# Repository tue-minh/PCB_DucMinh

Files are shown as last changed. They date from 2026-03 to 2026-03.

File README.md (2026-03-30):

<div align="center">
  <a href="image/pcb.jpg" target="_blank">
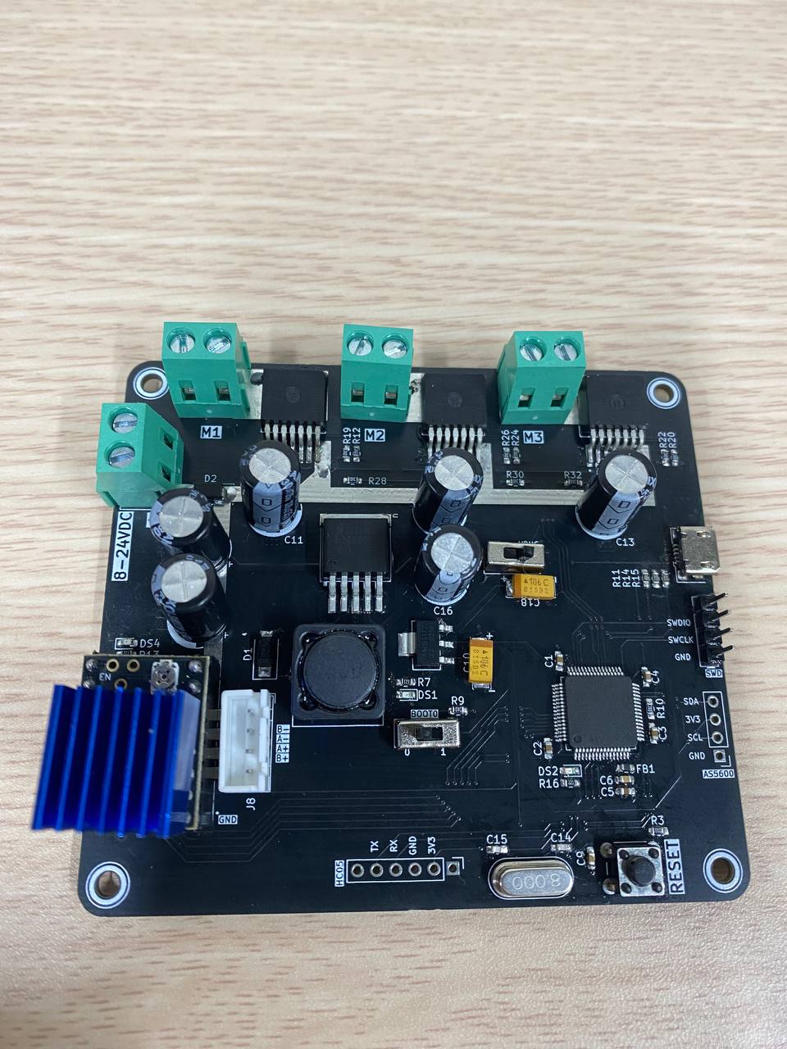
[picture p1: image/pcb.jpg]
Hardware Review
    
  </a>
  <p style="margin-top: 10px; color: #555; font-size: 0.9em; font-style: italic;">
    🔍 <b>Fig.</b> Hardware Review.
  </p>
</div>

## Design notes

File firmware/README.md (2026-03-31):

# Hướng dẫn sử dụng lệnh điều khiển

## 1. Điều khiển Stepper Motor

| Chức năng | Lệnh | Mô tả |
|---|---|---|
| Enable/Disable Driver | `step on` | Bật driver |
| | `step off` | Tắt driver |
| Set Direction | `step dir 0` | CCW
| | `step dir 1` | CW
| Set Speed | `step speed x` | Đặt tốc độ<br>*Lưu ý: 0 < x ≤ 10000* |
| Set MicroStep | `step ms x y` | Cài đặt MicroStep<br>**x**: 1/2 (MS1/MS2)<br>**y**: 1/0 (On/Off) |
| Enable PWM Output | `step start` | Bật xuất PWM |
| Disable PWM Output | `step stop` | Tắt xuất PWM |

## 2. Điều khiển DC Motor

| Chức năng | Lệnh | Mô tả |
|---|---|---|
| Set Speed (Single Channel) | `dc ch 1 x` | Đặt tốc độ cho kênh 1 <br>*Lưu ý: 0 < x ≤ 999* |
| | `dc ch 2 x` | Đặt tốc độ cho kênh 2 <br>*Lưu ý: 0 < x ≤ 999 |
| | `dc ch 3 x` | Đặt tốc độ cho kênh 3 <br>*Lưu ý: 0 < x ≤ 999 |
| Enable PWM Output | `dc start 1` | Bật PWM cho kênh 1 |
| | `dc start 2` | Bật PWM cho kênh 2 |
| | `dc start 3` | Bật PWM cho kênh 3 |
| Disable PWM Output | `dc stop 1` | Tắt PWM cho kênh 1 |
| | `dc stop 2` | Tắt PWM cho kênh 2 |
| | `dc stop 3` | Tắt PWM cho kênh 3 |

**Ghi chú:**
- Các lệnh `dc ch` dùng để đặt tốc độ cho từng kênh riêng lẻ.
- Các lệnh `dc start` dùng để bật xuất PWM cho từng kênh.

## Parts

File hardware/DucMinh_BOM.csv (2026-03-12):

Reference | Value | Footprint | Qty
C1,C2,C3,C4,C5,C9 | 100nf | Capacitor_SMD:C_0603_1608Metric_Pad1.08x0.95mm_HandSolder | 6 | Có s?n
C6 | 1uf | Capacitor_SMD:C_0603_1608Metric_Pad1.08x0.95mm_HandSolder | 1
C8,C16 | 330uF | Capacitor_THT:CP_Radial_D8.0mm_P5.00mm | 2
C10,C18 | 10uf | tue_tantalum6032:tue_tantalum_6032 | 2 | Thi?u
C11,C12,C13 | 330uf | Capacitor_THT:CP_Radial_D8.0mm_P5.00mm | 3
C14,C15 | 20pf | Capacitor_SMD:C_0603_1608Metric_Pad1.08x0.95mm_HandSolder | 2 | Có s?n
C17 | 470uf | Capacitor_THT:CP_Radial_D8.0mm_P5.00mm | 1 | Thi?u
D1,D2 | SS34 | Diode_SMD:D_SMA | 2
DS1 | LED_PWR | LED_SMD:LED_0603_1608Metric_Pad1.05x0.95mm_HandSolder | 1 | Có s?n
DS2 | LED_PC13 | LED_SMD:LED_0603_1608Metric_Pad1.05x0.95mm_HandSolder | 1
DS4 | LED_TMC_EN | LED_SMD:LED_0603_1608Metric_Pad1.05x0.95mm_HandSolder | 1
FB1 | 120R | Resistor_SMD:R_0603_1608Metric | 1
J1 | Power | tue_TerminalBlock:TerminalBlock_bornier-2_P5.08mm | 1
J2 | M1 | tue_TerminalBlock:TerminalBlock_bornier-2_P5.08mm | 1
J3 | USB_B_Micro | Connector_USB:USB_Micro-B_Amphenol_10118193-0001LF_Horizontal | 1
J4 | M2 | tue_TerminalBlock:TerminalBlock_bornier-2_P5.08mm | 1
J5 | M3 | tue_TerminalBlock:TerminalBlock_bornier-2_P5.08mm | 1
J6 | AS5600 | Connector_PinHeader_2.54mm:PinHeader_1x04_P2.54mm_Vertical | 1
J7 | STLink | Connector_PinHeader_2.54mm:PinHeader_1x04_P2.54mm_Vertical | 1
J8 | Stepper_Motor | Connector_JST:JST_XH_B4B-XH-A_1x04_P2.50mm_Vertical | 1
J10 | HC05 | Connector_PinHeader_2.54mm:PinHeader_1x06_P2.54mm_Vertical | 1
J11 | PWR_Selection | tue_switch-SS12D00:tue_SS12D00_3P_2.5mm | 1 | Thi?u
J12 | BOOT0 | tue_switch-SS12D00:tue_SS12D00_3P_2.5mm | 1
L1 | CDRH127/LDNP-47uH | tue_inductor_smd:tue__CDRH127LDNP-470MC_SUM | 1
R3,R9,R10,R12,R19,R20,R22,R24,R26,R28,R30,R32 | 10k | Resistor_SMD:R_0603_1608Metric_Pad0.98x0.95mm_HandSolder | 12 | Có s?n
R7,R13,R16 | 1k | Resistor_SMD:R_0603_1608Metric_Pad0.98x0.95mm_HandSolder | 3
R11 | 1k5 | Resistor_SMD:R_0603_1608Metric_Pad0.98x0.95mm_HandSolder | 1
R14,R15 | 20-22R | Resistor_SMD:R_0603_1608Metric_Pad0.98x0.95mm_HandSolder | 2
SW1 | SW_Push | Button_Switch_THT:SW_PUSH_6mm | 1
U2 | AMS1117-3.3 | tue_ams1117:SOT_AMS_ADS | 1 | Thi?u
U3 | LM2596SX-5.0/NOPB | tue_lm2596hvs:tue_lm2596 | 1
U4 | TMC2209_SILENTSTEPSTICK | tue_TMC2209:tue_TMC2209 | 1
U5,U8,U10 | BTS7960B | tue_bts7960b:DPAK127P1490X440-8N | 3
U6 | STM32F103RCT6 | tue_stm32f103rct6:QFP50P1200X1200X160-64N | 1
Y1 | 8 MHz | Crystal:Crystal_HC49-4H_Vertical | 1

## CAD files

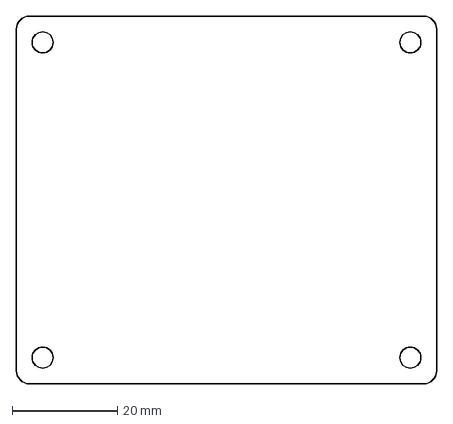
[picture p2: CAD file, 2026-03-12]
hardware/Drawing1.dxf
80.0 x 70.0 mm

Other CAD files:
hardware/Drawing1.dwg

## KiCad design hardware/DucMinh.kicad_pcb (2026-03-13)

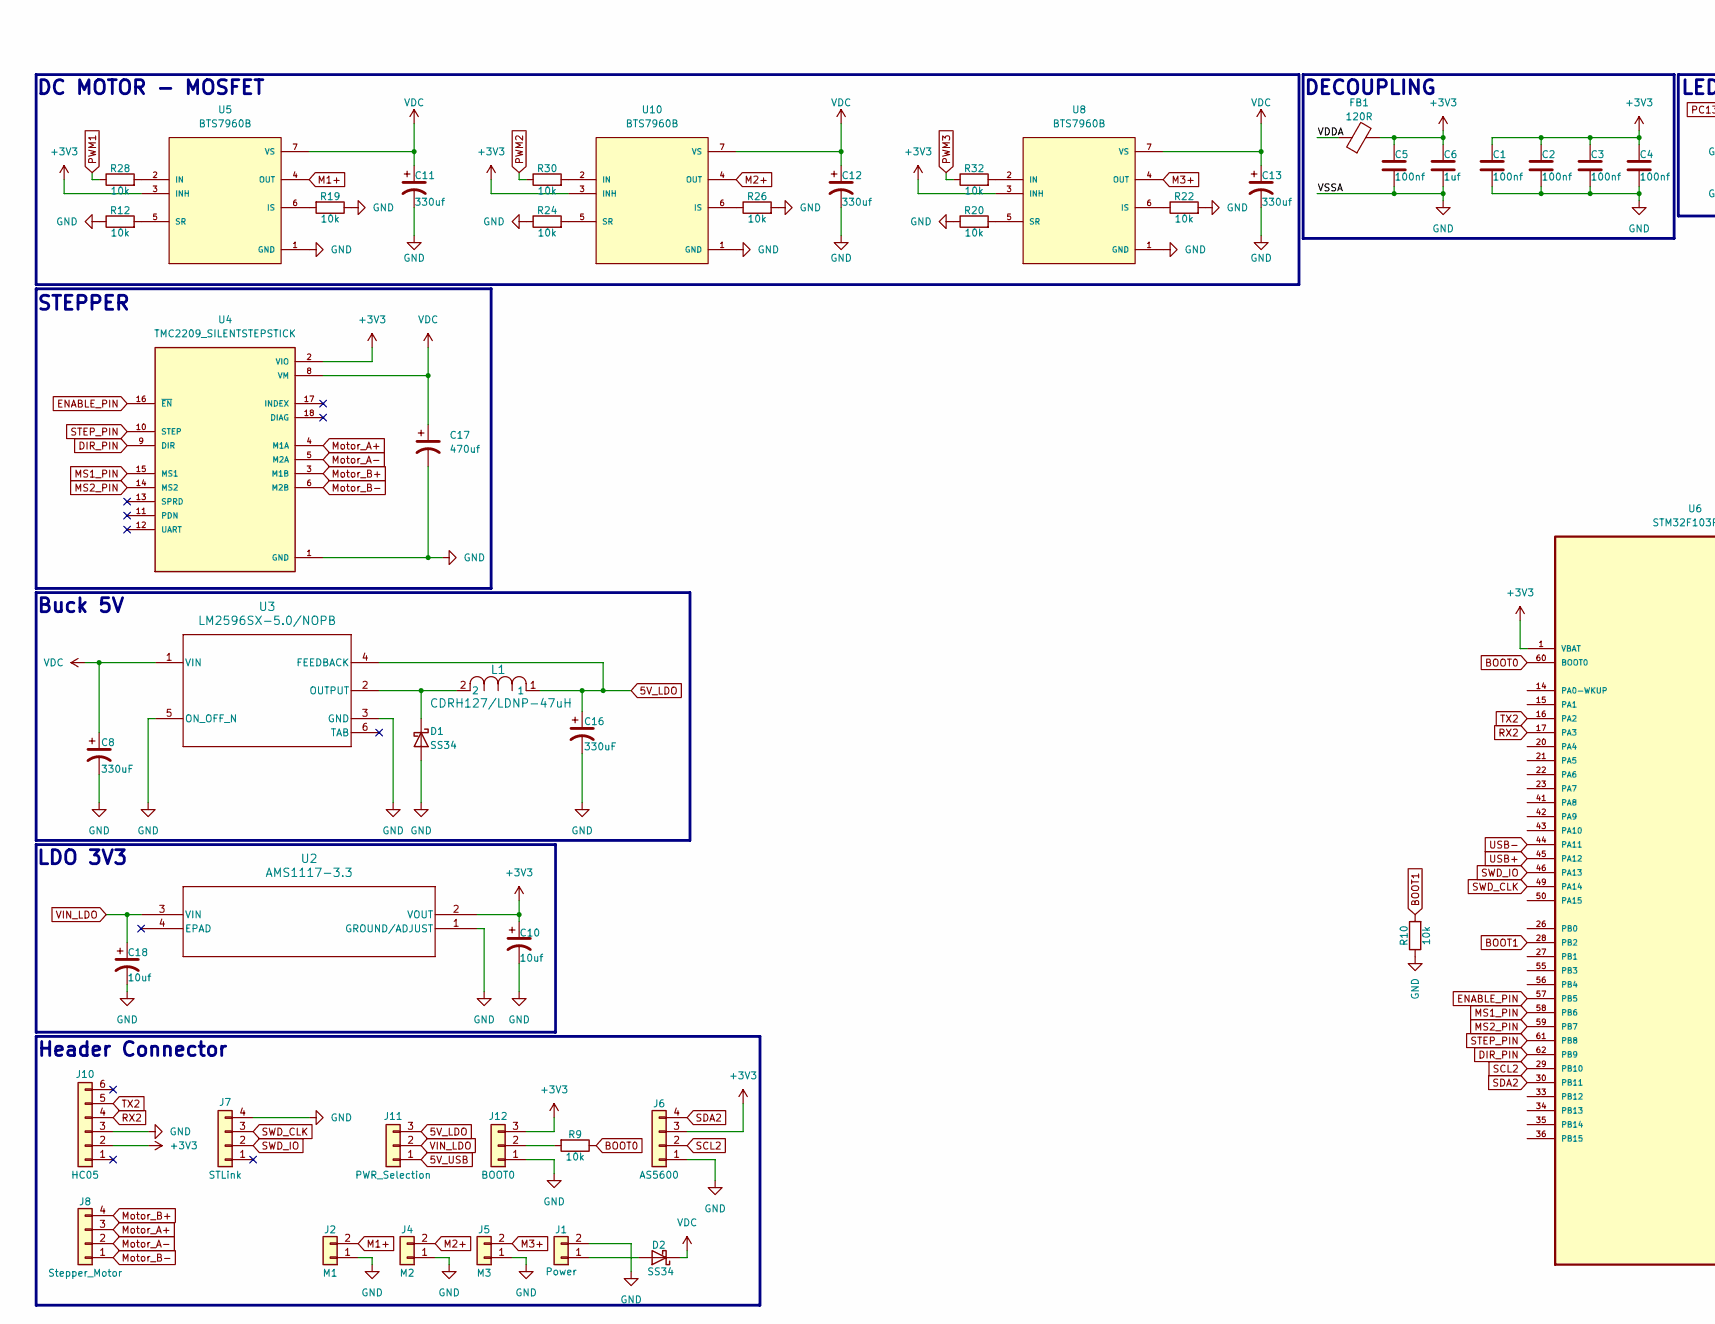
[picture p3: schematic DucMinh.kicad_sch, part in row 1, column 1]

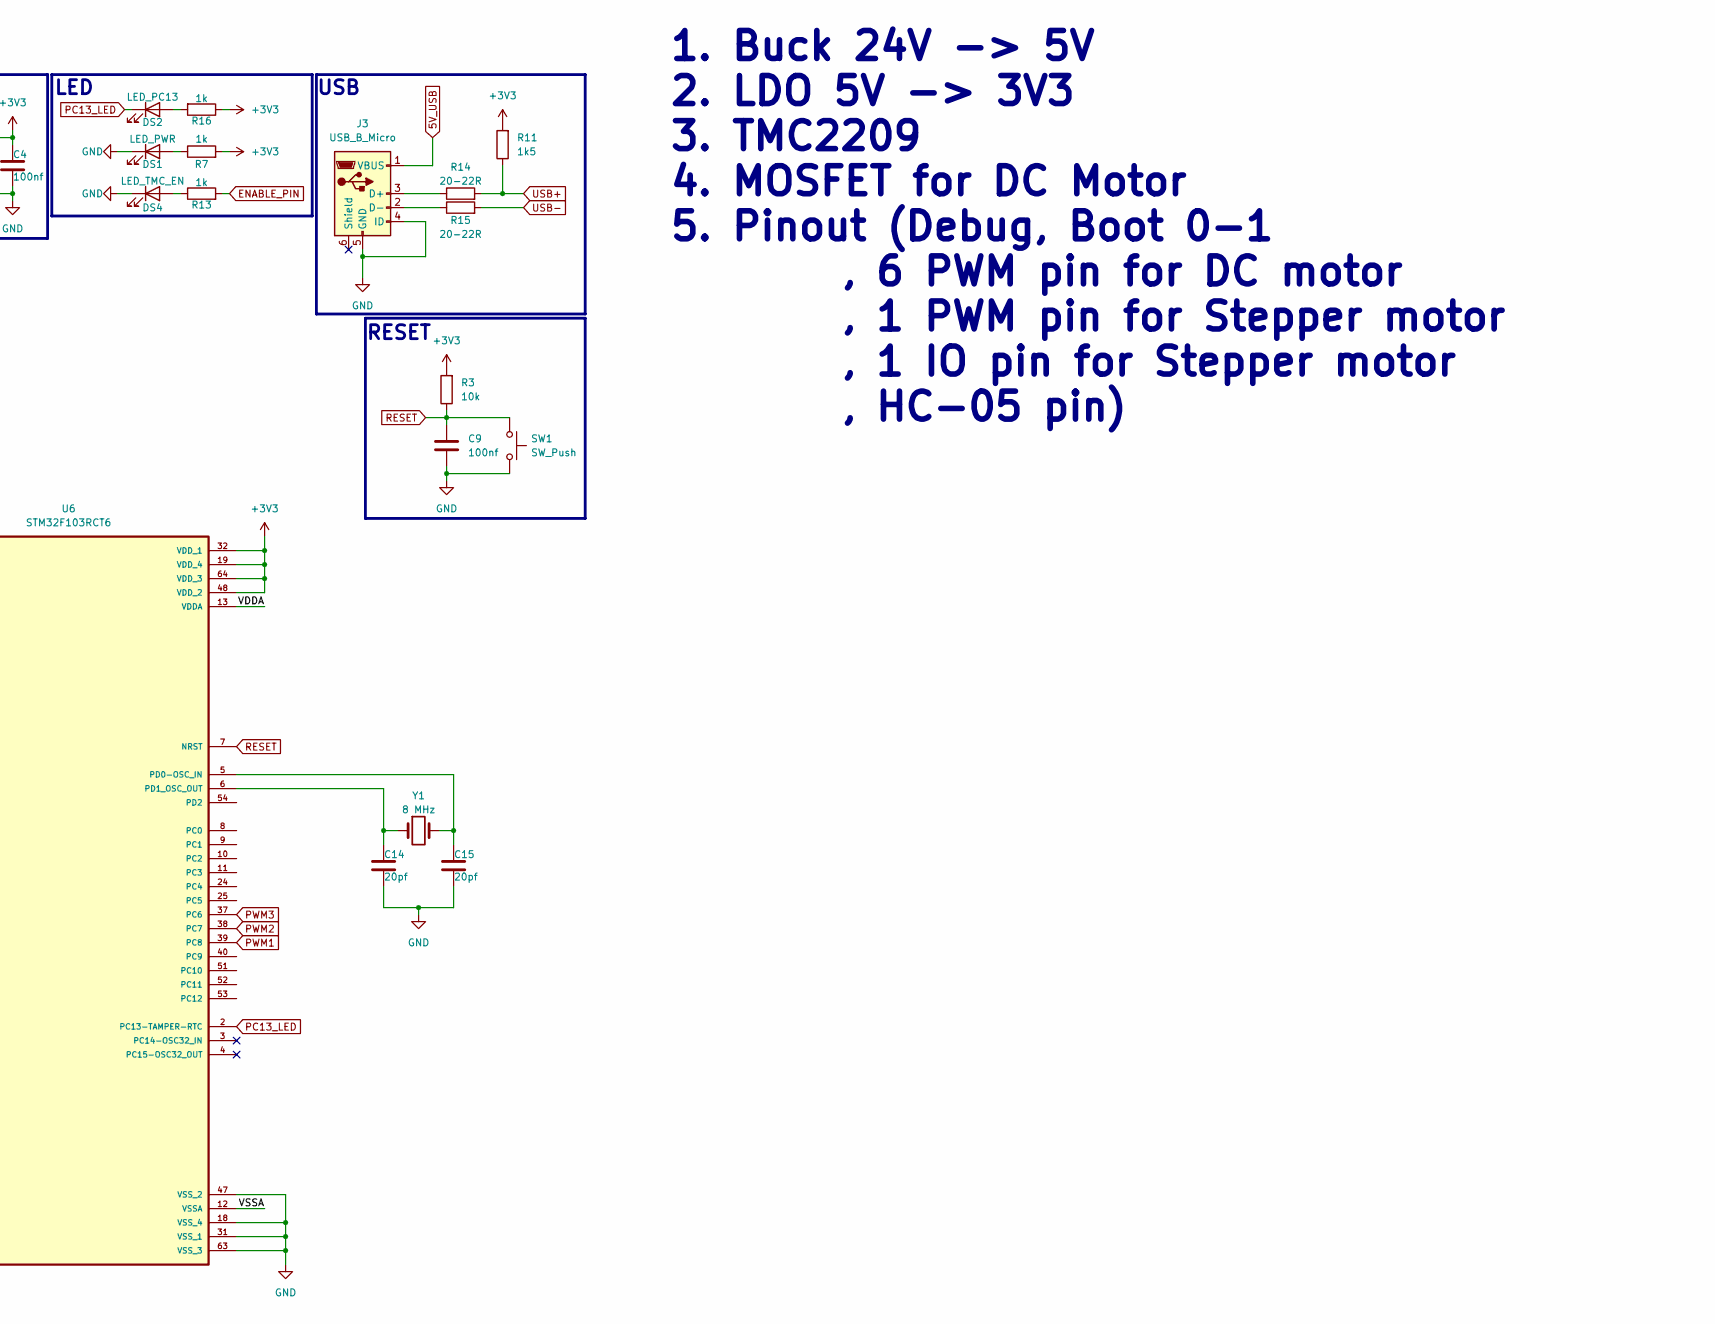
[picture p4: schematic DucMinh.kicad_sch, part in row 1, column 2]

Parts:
C1, C2, C3, C4, C5, C9: 100nf; C_0603_1608Metric_Pad1.08x0.95mm_HandSolder
C6: 1uf; C_0603_1608Metric_Pad1.08x0.95mm_HandSolder
C8, C16: 330uF; CP_Radial_D8.0mm_P5.00mm
C10, C18: 10uf; tue_tantalum_6032
C11, C12, C13: 330uf; CP_Radial_D8.0mm_P5.00mm
C14, C15: 20pf; C_0603_1608Metric_Pad1.08x0.95mm_HandSolder
C17: 470uf; CP_Radial_D8.0mm_P5.00mm
D1, D2: SS34; D_SMA
DS1: LED_PWR; LED_0603_1608Metric_Pad1.05x0.95mm_HandSolder
DS2: LED_PC13; LED_0603_1608Metric_Pad1.05x0.95mm_HandSolder
DS4: LED_TMC_EN; LED_0603_1608Metric_Pad1.05x0.95mm_HandSolder
FB1: 120R; R_0603_1608Metric
J1: Power; TerminalBlock_bornier-2_P5.08mm
J2: M1; TerminalBlock_bornier-2_P5.08mm
J3: USB_B_Micro; USB_Micro-B_Amphenol_10118193-0001LF_Horizontal
J4: M2; TerminalBlock_bornier-2_P5.08mm
J5: M3; TerminalBlock_bornier-2_P5.08mm
J6: AS5600; PinHeader_1x04_P2.54mm_Vertical
J7: STLink; PinHeader_1x04_P2.54mm_Vertical
J8: Stepper_Motor; JST_XH_B4B-XH-A_1x04_P2.50mm_Vertical
J10: HC05; PinHeader_1x06_P2.54mm_Vertical
J11: PWR_Selection; tue_SS12D00_3P_2.5mm
J12: BOOT0; tue_SS12D00_3P_2.5mm
L1: CDRH127/LDNP-47uH; tue__CDRH127LDNP-470MC_SUM
R3, R9, R10, R12, R19, R20, R22, R24, R26, R28, R30, R32: 10k; R_0603_1608Metric_Pad0.98x0.95mm_HandSolder
R7, R13, R16: 1k; R_0603_1608Metric_Pad0.98x0.95mm_HandSolder
R11: 1k5; R_0603_1608Metric_Pad0.98x0.95mm_HandSolder
R14, R15: 20-22R; R_0603_1608Metric_Pad0.98x0.95mm_HandSolder
SW1: SW_Push; SW_PUSH_6mm
U2: AMS1117-3.3; SOT_AMS_ADS
U3: LM2596SX-5.0/NOPB; tue_lm2596
U4: TMC2209_SILENTSTEPSTICK; tue_TMC2209; PARTREV 1.20
U5, U8, U10: BTS7960B; DPAK127P1490X440-8N; PARTREV 1.1
U6: STM32F103RCT6; QFP50P1200X1200X160-64N
Y1: 8 MHz; Crystal_HC49-4H_Vertical

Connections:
5V_LDO: C16.1, J11.3, L1.1, U3.4 (FEEDBACK)
5V_USB: J3.1 (VBUS), J11.1
+3V3: C1.1, C2.1, C3.1, C4.1, C5.1, C6.1, C10.1, FB1.2, J6.3, J10.2, J12.3, R3.2, R7.2, R11.2, R16.1, U2.2 (VOUT), U4.2 (VIO), U5.3 (INH), U6.1 (VBAT), U6.19 (VDD_4), U6.32 (VDD_1), U6.48 (VDD_2), U6.64 (VDD_3), U8.3 (INH), U10.3 (INH)
/VDDA: FB1.1, U6.13 (VDDA)
BOOT0: R9.1, U6.60 (BOOT0)
BOOT1: R10.2, U6.28 (PB2)
DIR_PIN: U4.9 (DIR), U6.62 (PB9)
ENABLE_PIN: R13.2, U4.16 (~EN), U6.57 (PB5)
GND: C1.2, C2.2, C3.2, C4.2, C5.2, C6.2, C8.2, C9.2, C10.2, C11.2, C12.2, C13.2, C14.2, C15.2, C16.2, C17.2, C18.2, D1.2 (A), DS1.1 (K), DS4.1 (K), J1.2, J2.1, J3.4 (ID), J3.5 (GND), J4.1, J5.1, J6.1, J7.4, J10.3, J12.1, R10.1, R12.1, R19.1, R20.1, R22.2, R24.1, R26.2, SW1.2, U2.1 (GROUND/ADJUST), U3.3 (GND), U3.5 (ON_OFF_N), U4.1 (GND), U4.7 (GND), U5.1 (GND), U6.12 (VSSA), U6.18 (VSS_4), U6.31 (VSS_1), U6.47 (VSS_2), U6.63 (VSS_3), U8.1 (GND), U10.1 (GND)
M1+: J2.2, U5.4 (OUT), U5.8 (OUT)
M2+: J4.2, U10.4 (OUT), U10.8 (OUT)
M3+: J5.2, U8.4 (OUT), U8.8 (OUT)
MS1_PIN: U4.15 (MS1), U6.58 (PB6)
MS2_PIN: U4.14 (MS2), U6.59 (PB7)
Motor_A+: J8.3, U4.4 (M1A)
Motor_A-: J8.2, U4.5 (M2A)
Motor_B+: J8.4, U4.3 (M1B)
Motor_B-: J8.1, U4.6 (M2B)
unnamed: D1.1 (K), L1.2, U3.2 (OUTPUT)
unnamed: D2.2 (A), J1.1
unnamed: DS1.2 (A), R7.1
unnamed: DS2.2 (A), R16.2
unnamed: DS4.2 (A), R13.1
unnamed: J3.3 (D+), R14.1
unnamed: J3.2 (D-), R15.1
unnamed: J12.2, R9.2
unnamed: R28.2, U5.2 (IN)
unnamed: R19.2, U5.6 (IS)
unnamed: R12.2, U5.5 (SR)
unnamed: C15.1, U6.5 (PD0-OSC_IN), Y1.2
unnamed: C14.1, U6.6 (PD1_OSC_OUT), Y1.1
unnamed: R32.2, U8.2 (IN)
unnamed: R22.1, U8.6 (IS)
unnamed: R20.2, U8.5 (SR)
unnamed: R30.2, U10.2 (IN)
unnamed: R26.1, U10.6 (IS)
unnamed: R24.2, U10.5 (SR)
PC13_LED: DS2.1 (K), U6.2 (PC13-TAMPER-RTC)
PWM1: R28.1, U6.39 (PC8)
PWM2: R30.1, U6.38 (PC7)
PWM3: R32.1, U6.37 (PC6)
RESET: C9.1, R3.1, SW1.1, U6.7 (NRST)
RX2: J10.4, U6.17 (PA3)
SCL2: J6.2, U6.29 (PB10)
SDA2: J6.4, U6.30 (PB11)
STEP_PIN: U4.10 (STEP), U6.61 (PB8)
SWD_CLK: J7.3, U6.49 (PA14)
SWD_IO: J7.2, U6.46 (PA13)
TX2: J10.5, U6.16 (PA2)
USB+: R11.1, R14.2, U6.45 (PA12)
USB-: R15.2, U6.44 (PA11)
VDC: C8.1, C11.1, C12.1, C13.1, C17.1, D2.1 (K), U3.1 (VIN), U4.8 (VM), U5.7 (VS), U8.7 (VS), U10.7 (VS)
VIN_LDO: C18.1, J11.2, U2.3 (VIN)

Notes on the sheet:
DECOUPLING
Buck 5V
LDO 3V3
RESET
STEPPER
Header Connector
1. Buck 24V -> 5V 2. LDO 5V -> 3V3 3. TMC2209 4. MOSFET for DC Motor 5. Pinout (Debug, Boot 0-1 , 6 PWM pin for DC motor , 1 PWM pin for Stepper motor , 1 IO pin for Stepper motor , HC-05 pin)
DC MOTOR - MOSFET
LED
USB

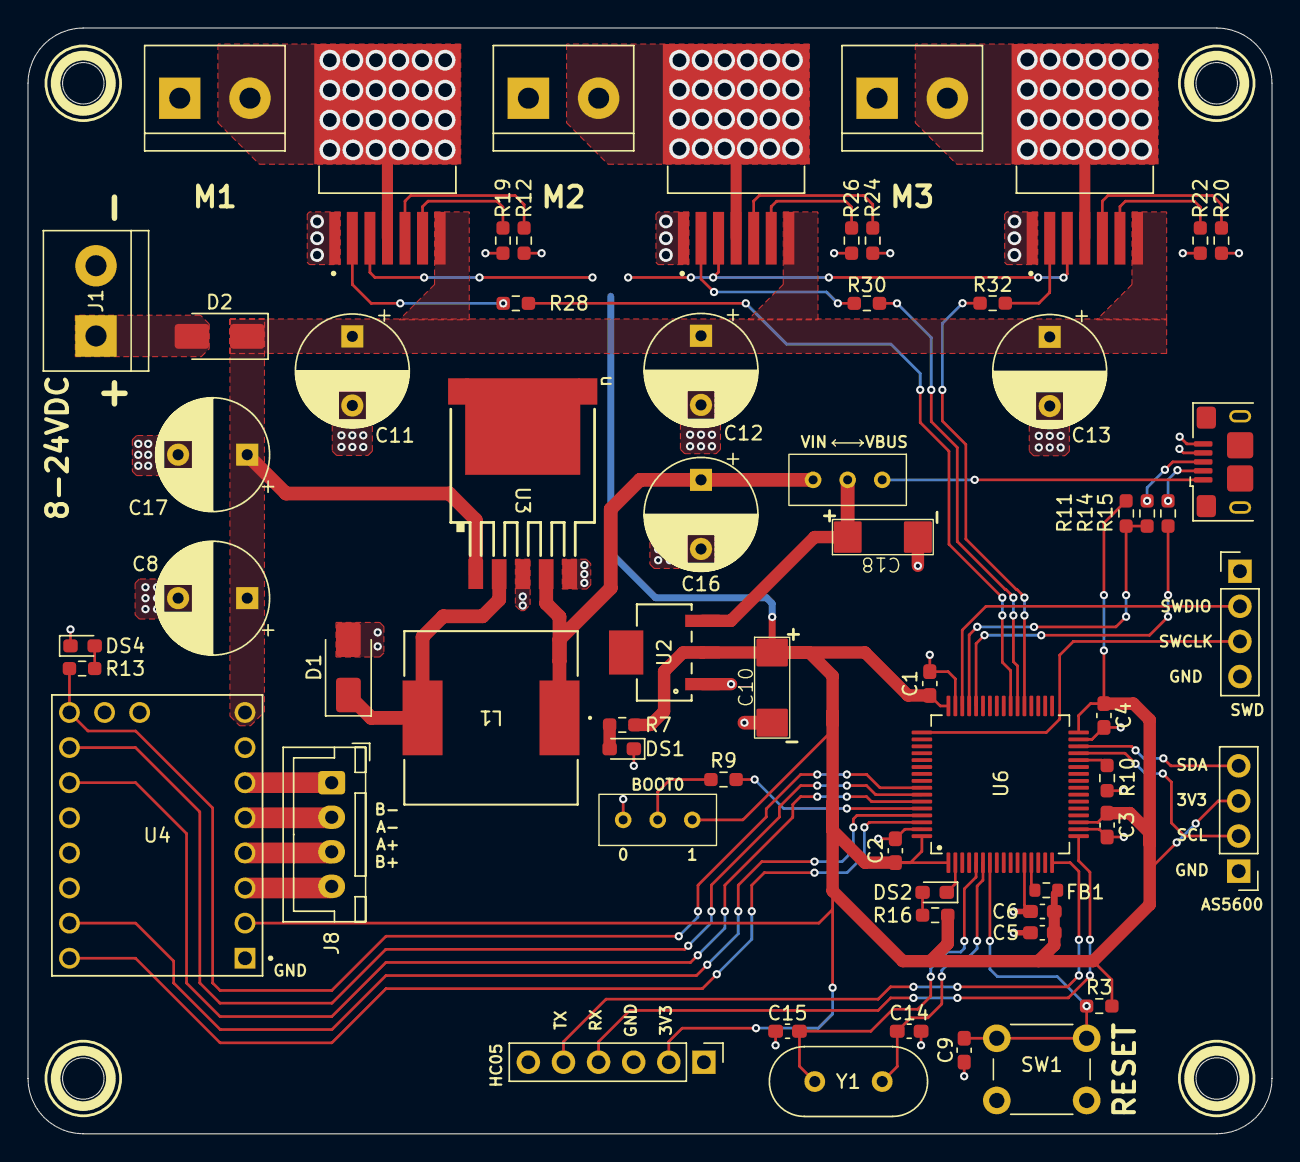
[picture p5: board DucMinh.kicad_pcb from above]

Board: 2 copper layers, 90.0 x 80.0 mm, 62 parts (0 on the bottom side), 53 nets.

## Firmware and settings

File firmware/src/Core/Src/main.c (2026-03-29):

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
/* Includes ------------------------------------------------------------------*/
#include "main.h"
#include "tim.h"
#include "usb_device.h"
#include "gpio.h"

/* USER CODE BEGIN Includes */
#include "usbd_cdc_if.h"
#include <stdio.h>
#include <string.h>
#include <stdlib.h>
#include <stdarg.h>
/* USER CODE END Includes */

/* USER CODE BEGIN PTD */
typedef struct
{
  char *data;
  uint32_t length;
} String;
typedef struct
{
  char *name;
  void (*handler)(int argc, char **argv);
  char *description;
} Command_t;
/* USER CODE END PTD */

/* USER CODE BEGIN PD */
#define STEP_PWM_PERIOD 1000
#define SERIAL_BUFFER_SIZE 256
/* USER CODE END PD */


/* USER CODE BEGIN PV */
static uint8_t serial_buffer[SERIAL_BUFFER_SIZE];
static uint32_t serial_buffer_index = 0;
static uint8_t serial_available_flag = 0;
uint8_t motor_speed = 0;
uint8_t stepper_enabled = 0;
uint8_t stepper_direction = 0;
uint32_t stepper_speed_hz = 100; // steps/seccond
/* USER CODE END PV */

void SystemClock_Config(void);
/* USER CODE BEGIN PFP */
uint8_t Serial_available(void);
int16_t Serial_read(void);
uint32_t Serial_readBytes(uint8_t *buffer, uint32_t length);
String Serial_readStringUntil(char terminator);
String Serial_readString(void);
int32_t Serial_parseInt(void);
float Serial_parseFloat(void);
// void Serial_print(const char *format, ...);
// void Serial_println(const char *format, ...);
// void Serial_print_int(int32_t value);
// void Serial_print_float(float value, uint8_t decimal_places);
// void Serial_println_void(void);
void Serial_flush(void);
void USB_CDC_RxHandler(uint8_t *Buf, uint32_t Len);
static void Stepper_Enable(void);
static void Stepper_Disable(void);
static void Stepper_Set_Direction(uint8_t dir);
static void Stepper_Set_Speed(uint32_t hz);
static void Stepper_Start(void);
static void Stepper_Stop(void);
// static void DC_Start(void);
// static void DC_Stop(void);
// static void DC_Set_Speed(uint8_t speed);

/* USER CODE END PFP */

/* USER CODE BEGIN 0 */
void USB_CDC_RxHandler(uint8_t *Buf, uint32_t Len)
{
  if (Len > 0)
  {
    for (uint32_t i = 0; i < Len; i++)
    {
      if (serial_buffer_index < SERIAL_BUFFER_SIZE)
      {
        serial_buffer[serial_buffer_index++] = Buf[i];
      }
    }
    serial_available_flag = 1;
  }
}
// Serial available - kiểm tra dữ liệu có sẵn
uint8_t Serial_available(void)
{
  return (serial_available_flag && (serial_buffer_index > 0));
}

static void Serial_write(uint8_t *data, uint16_t len)
{
  // gửi nếu USB rảnh, không thì bỏ
  if (CDC_Transmit_FS(data, len) == USBD_OK)
  {
  }
}
void Serial_print(const char *fmt, ...)
{
  char buffer[128];

  va_list args;
  va_start(args, fmt);
  vsnprintf(buffer, sizeof(buffer), fmt, args);
  va_end(args);

  Serial_write((uint8_t *)buffer, strlen(buffer));
}
void Serial_println(const char *fmt, ...)
{
  char buffer[128];

  va_list args;
  va_start(args, fmt);
  vsnprintf(buffer, sizeof(buffer), fmt, args);
  va_end(args);

  uint16_t len = strlen(buffer);

  // thêm newline
  buffer[len++] = '\r';
  buffer[len++] = '\n';
  buffer[len] = '\0';

  Serial_write((uint8_t *)buffer, len);
}

// Đọc 1 byte từ buffer
int16_t Serial_read(void)
{
  if (!Serial_available())
    return -1;

  uint8_t data = serial_buffer[0];

  // Dịch buffer lên
  for (uint32_t i = 0; i < serial_buffer_index - 1; i++)
  {
    serial_buffer[i] = serial_buffer[i + 1];
  }
  serial_buffer_index--;

  if (serial_buffer_index == 0)
  {
    serial_available_flag = 0;
  }

  return data;
}

// Đọc dữ liệu vào buffer
uint32_t Serial_readBytes(uint8_t *buffer, uint32_t length)
{
  uint32_t count = 0;
  while (count < length && Serial_available())
  {
    int16_t data = Serial_read();
    if (data >= 0)
    {
      buffer[count++] = (uint8_t)data;
    }
    else
    {
      break;
    }
  }
  return count;
}

// Đọc 1 dòng (đến \n hoặc \r\n)
String Serial_readStringUntil(char terminator)
{
  String result = {0};
  char temp[SERIAL_BUFFER_SIZE];
  uint32_t index = 0;

  while (index < SERIAL_BUFFER_SIZE - 1 && Serial_available())
  {
    int16_t c = Serial_read();
    if (c < 0)
      break;

    if (c == terminator || c == '\n')
    {
      if (c == '\n' && index > 0 && temp[index - 1] == '\r')
      {
        index--; // Bỏ qua \r
      }
      break;
    }

    temp[index++] = (char)c;
  }

  temp[index] = '\0';
  result.data = malloc(index + 1);
  if (result.data)
  {
    strcpy(result.data, temp);
    result.length = index;
  }

  return result;
}

// Đọc chuỗi (không có ký tự kết thúc)
String Serial_readString(void)
{
  return Serial_readStringUntil('\n');
}

// Parse string thành số nguyên
int32_t Serial_parseInt(void)
{
  String str = Serial_readStringUntil('\n');
  if (str.data)
  {
    int32_t value = atoi(str.data);
    free(str.data);
    return value;
  }
  return 0;
}

// Parse string thành số thực
float Serial_parseFloat(void)
{
  String str = Serial_readStringUntil('\n');
  if (str.data)
  {
    float value = atof(str.data);
    free(str.data);
    return value;
  }
  return 0;
}

// // In ra Serial (giống Serial.print)
// void Serial_print(const char *format, ...)
// {
//   char buffer[256];
//   va_list args;
//   va_start(args, format);
//   vsnprintf(buffer, sizeof(buffer), format, args);
//   va_end(args);

//   if (CDC_Transmit_FS((uint8_t *)buffer, strlen(buffer)) == USBD_OK){}
// }

// // In ra Serial có xuống dòng
// void Serial_println(const char *format, ...)
// {
//   char buffer[256];
//   va_list args;
//   va_start(args, format);
//   vsnprintf(buffer, sizeof(buffer), format, args);
//   va_end(args);

//   char output[260];
//   snprintf(output, sizeof(output), "%s\r\n", buffer);
//   if (CDC_Transmit_FS((uint8_t *)output, strlen(output)) == USBD_OK){}
// }

// // In số nguyên
// void Serial_print_int(int32_t value)
// {
//   char buffer[32];
//   snprintf(buffer, sizeof(buffer), "%ld", value);
//   if (CDC_Transmit_FS((uint8_t *)buffer, strlen(buffer)) == USBD_OK){}
// }

// // In số thực
// void Serial_print_float(float value, uint8_t decimal_places)
// {
//   char buffer[64];
//   snprintf(buffer, sizeof(buffer), "%.*f", decimal_places, value);
//   if (CDC_Transmit_FS((uint8_t *)buffer, strlen(buffer)) == USBD_OK){}
// }

// // In xuống dòng
// void Serial_println_void(void)
// {
//   if (CDC_Transmit_FS((uint8_t *)"\r\n", 2) == USBD_OK){}
// }

// Flush buffer
void Serial_flush(void)
{
  serial_buffer_index = 0;
  serial_available_flag = 0;
}
static void Stepper_Enable(void)
{
  stepper_enabled = 1;
  HAL_GPIO_WritePin(STEP_EN_GPIO_Port, STEP_EN_Pin, GPIO_PIN_RESET);
}
static void Stepper_Disable(void)
{
  stepper_enabled = 0;
  HAL_GPIO_WritePin(STEP_EN_GPIO_Port, STEP_EN_Pin, GPIO_PIN_SET);
  HAL_TIM_PWM_Stop(&htim4, TIM_CHANNEL_3);
}
static void Stepper_Set_Direction(uint8_t dir)
{
  stepper_direction = dir;
  HAL_GPIO_WritePin(STEP_DIR_GPIO_Port, STEP_DIR_Pin, dir ? GPIO_PIN_SET : GPIO_PIN_RESET);
}
static void Stepper_Set_Speed(uint32_t hz)
{
  if (hz > 0 && hz <= 10000) // Giới hạn 10kHz
  {
    stepper_speed_hz = hz;

    // Tính toán lại tần số PWM
    // Clock TIM4 = 72MHz / (Prescaler+1) = 72MHz / 72 = 1MHz
    // Period = 1MHz / (hz * 2) vì cần 2 xung PWM cho 1 step?
    // Thực tế: mỗi chu kỳ PWM = 1 step, nhưng cần 50% duty để có xung lên xuống
    // Nên tần số PWM = tần số step
    uint32_t period = 1000000 / hz; // 1MHz / hz

    if (period < 2)
      period = 2; // Giới hạn period tối thiểu

    __HAL_TIM_SET_AUTORELOAD(&htim4, period - 1);
    __HAL_TIM_SET_COMPARE(&htim4, TIM_CHANNEL_3, (period - 1) / 2);
  }
}
static void Stepper_Start(void)
{
  if (stepper_enabled)
  {
    HAL_TIM_PWM_Start(&htim4, TIM_CHANNEL_3);
  }
}
static void Stepper_Stop(void)
{
  HAL_TIM_PWM_Stop(&htim4, TIM_CHANNEL_3);
  HAL_GPIO_WritePin(GPIOB, GPIO_PIN_8, GPIO_PIN_RESET);
}

// Hàm split string thành các token
uint8_t split_command(char *command, char **argv, uint8_t max_args)
{
  uint8_t argc = 0;
  char *token = strtok(command, " ");

  while (token != NULL && argc < max_args)
  {
    argv[argc++] = token;
    token = strtok(NULL, " ");
  }

  return argc;
}

// Xử lý lệnh "help"
void cmd_help(int argc, char **argv)
{
  Serial_println("======= Available Commands =======");
  Serial_println("  help              - Show this help");
  Serial_println("  status            - Show motor status");
  Serial_println("  step on/off       - Enable/disable stepper motor");
  Serial_println("  step dir [0/1]    - Set stepper direction (0=CCW, 1=CW)");
  Serial_println("  step speed [hz]   - Set stepper speed (1-10000 Hz)");
  Serial_println("  step start/stop   - Start/stop stepper motor");
  Serial_println("  dc speed [0-255]  - Set DC motor speed (PWM value)");
  Serial_println("  dc ch [1-3] [val] - Set DC motor channel value");
  Serial_println("  echo [text]       - Echo back text");
  Serial_println("======= Available Commands =======");
}

// Xử lý lệnh "status"
void cmd_status(int argc, char **argv)
{
  Serial_println("======= Motor Status =======");
  Serial_print("Stepper Enabled: ");
  Serial_println(stepper_enabled ? "YES" : "NO");
  Serial_print("Stepper Direction: ");
  Serial_println(stepper_direction ? "CW" : "CCW");
  Serial_print("Stepper Speed: ", stepper_speed_hz);
  // Serial_print(stepper_speed_hz);
  Serial_println(" Hz");
  Serial_print("Stepper PWM State: ");
  Serial_println(HAL_TIM_PWM_GetState(&htim4) == HAL_TIM_STATE_READY ? "Stopped" : "Running");
  Serial_println("======= Motor Status =======");
}

// Xử lý lệnh "step"
void cmd_step(int argc, char **argv)
{
  if (argc < 2)
  {
    Serial_println("Usage: step [on/off/dir/speed/start/stop]");
    return;
  }

  if (strcmp(argv[1], "on") == 0)
  {
    Stepper_Enable();
    Serial_println("Stepper enabled");
  }
  else if (strcmp(argv[1], "off") == 0)
  {
    Stepper_Disable();
    Serial_println("Stepper disabled");
  }
  else if (strcmp(argv[1], "dir") == 0 && argc >= 3)
  {
    uint8_t dir = atoi(argv[2]);
    Stepper_Set_Direction(dir);
    Serial_print("Stepper direction set to ");
    Serial_println(dir ? "CW" : "CCW");
  }
  else if (strcmp(argv[1], "speed") == 0 && argc >= 3)
  {
    uint32_t speed = atoi(argv[2]);
    Stepper_Set_Speed(speed);
    Serial_print("Stepper speed set to ", speed);
    // Serial_print(speed);
    Serial_println(" Hz");
  }
  else if (strcmp(argv[1], "start") == 0)
  {
    Stepper_Start();
    Serial_println("Stepper started");
  }
  else if (strcmp(argv[1], "stop") == 0)
  {
    Stepper_Stop();
    Serial_println("Stepper stopped");
  }
  else if (strcmp(argv[1], "ms") == 0 && argc >= 4)
  {
    uint8_t ms_pin = atoi(argv[2]); // 1 hoặc 2
    uint8_t state = atoi(argv[3]);  // 0 hoặc 1

    if (state > 1)
    {
      Serial_println("Invalid state (0 or 1)");
      return;
    }

    GPIO_PinState gpio_state = state ? GPIO_PIN_SET : GPIO_PIN_RESET;

    switch (ms_pin)
    {
    case 1:
      HAL_GPIO_WritePin(STEP_MS1_GPIO_Port, STEP_MS1_Pin, gpio_state);
      Serial_println("MS1 set to %d", state);
      break;

    case 2:
      HAL_GPIO_WritePin(STEP_MS2_GPIO_Port, STEP_MS2_Pin, gpio_state);
      Serial_println("MS2 set to %d", state);
      break;

    default:
      Serial_println("Invalid MS pin (1 or 2)");
      break;
    }
  }
  else
  {
    Serial_println("Invalid step subcommand");
  }
}

// Xử lý lệnh "dc"
void cmd_dc(int argc, char **argv)
{
  if (argc < 2)
  {
    Serial_println("Usage: dc [speed/ch/start/stop] ...");
    return;
  }

  // ===== dc ch =====
  else if (strcmp(argv[1], "ch") == 0 && argc >= 4)
  {
    uint8_t channel = atoi(argv[2]);
    uint32_t value = atoi(argv[3]);

    if (value > 999)
      value = 999;

    switch (channel)
    {
    case 1:
      __HAL_TIM_SET_COMPARE(&htim8, TIM_CHANNEL_3, value);
      Serial_println("Channel 1 set to %lu", value);
      break;

    case 2:
      __HAL_TIM_SET_COMPARE(&htim8, TIM_CHANNEL_2, value);
      Serial_println("Channel 2 set to %lu", value);
      break;

    case 3:
      __HAL_TIM_SET_COMPARE(&htim8, TIM_CHANNEL_1, value);
      Serial_println("Channel 3 set to %lu", value);
      break;

    default:
      Serial_println("Invalid channel (1-3)");
    }
  }

  // ===== dc start =====
  else if (strcmp(argv[1], "start") == 0 && argc >= 3)
  {
    uint8_t channel = atoi(argv[2]);

    switch (channel)
    {
    case 1:
      HAL_TIM_PWM_Start(&htim8, TIM_CHANNEL_3);
      Serial_println("Channel 1 STARTED");
      break;

    case 2:
      HAL_TIM_PWM_Start(&htim8, TIM_CHANNEL_2);
      Serial_println("Channel 2 STARTED");
      break;

    case 3:
      HAL_TIM_PWM_Start(&htim8, TIM_CHANNEL_1);
      Serial_println("Channel 3 STARTED");
      break;

    default:
      Serial_println("Invalid channel (1-3)");
    }
  }

  // ===== dc stop =====
  else if (strcmp(argv[1], "stop") == 0 && argc >= 3)
  {
    uint8_t channel = atoi(argv[2]);

    switch (channel)
    {
    case 1:
      HAL_TIM_PWM_Stop(&htim8, TIM_CHANNEL_3);
      Serial_println("Channel 1 STOPPED");
      break;

    case 2:
      HAL_TIM_PWM_Stop(&htim8, TIM_CHANNEL_2);
      Serial_println("Channel 2 STOPPED");
      break;

    case 3:
      HAL_TIM_PWM_Stop(&htim8, TIM_CHANNEL_1);
      Serial_println("Channel 3 STOPPED");
      break;

    default:
      Serial_println("Invalid channel (1-3)");
    }
  }

  else
  {
    Serial_println("Invalid dc command");
  }
}

// Xử lý lệnh "echo"
void cmd_echo(int argc, char **argv)
{
  if (argc >= 2)
  {
    for (int i = 1; i < argc; i++)
    {
      Serial_print("%s", argv[i]);
      if (i < argc - 1)
        Serial_print(" ");
    }
    if (CDC_Transmit_FS((uint8_t *)"\r\n", 2) == USBD_OK)
    {
    }
  }
}

// Danh sách các lệnh
Command_t commands[] = {
    {"help", cmd_help, "Show help"},
    {"status", cmd_status, "Show status"},
    {"step", cmd_step, "Control stepper motor"},
    {"dc", cmd_dc, "Control DC motor"},
    {"echo", cmd_echo, "Echo text"},
    {NULL, NULL, NULL}};

// Tìm và thực thi lệnh
void process_command(char *command_str)
{
  // Xóa ký tự xuống dòng
  char *newline = strchr(command_str, '\n');
  if (newline)
    *newline = '\0';
  newline = strchr(command_str, '\r');
  if (newline)
    *newline = '\0';

  if (strlen(command_str) == 0)
    return;

  char *argv[10];
  uint8_t argc = split_command(command_str, argv, 10);

  if (argc == 0)
    return;

  // Tìm và thực thi lệnh
  for (int i = 0; commands[i].name != NULL; i++)
  {
    if (strcmp(argv[0], commands[i].name) == 0)
    {
      commands[i].handler(argc, argv);
      return;
    }
  }

  // Không tìm thấy lệnh
  Serial_print("Unknown command: ");
  Serial_println("%s", argv[0]);
  Serial_println("Type 'help' for available commands");
}

// Hàm xử lý chính cho USB commands (gọi trong main loop)
void Serial_process_commands(void)
{
  if (Serial_available())
  {
    String cmd = Serial_readString();
    if (cmd.data)
    {
      process_command(cmd.data);
      free(cmd.data);
    }
  }
}

// Hàm tiện ích: đọc số từ Serial (blocking với timeout)
int32_t Serial_readInt_timeout(uint32_t timeout_ms)
{
  uint32_t start = HAL_GetTick();
  String str = {0};
  char temp[32];
  uint32_t index = 0;

  while ((HAL_GetTick() - start) < timeout_ms)
  {
    if (Serial_available())
    {
      int16_t c = Serial_read();
      if (c >= 0)
      {
        if ((c >= '0' && c <= '9') || c == '-' || (c == '.' && index > 0))
        {
          if (index < 31)
            temp[index++] = (char)c;
        }
        else if (c == '\n' || c == ' ')
        {
          break;
        }
      }
    }
  }

  temp[index] = '\0';
  return atoi(temp);
}

// Hàm đọc chuỗi từ Serial (non-blocking)
uint8_t Serial_readString_nonblocking(char *buffer, uint32_t max_len)
{
  static uint32_t last_time = 0;
  static uint32_t index = 0;

  if (Serial_available())
  {
    int16_t c = Serial_read();
    if (c >= 0)
    {
      if (c == '\n' || c == '\r')
      {
        buffer[index] = '\0';
        index = 0;
        return 1;
      }
      else if (index < max_len - 1)
      {
        buffer[index++] = (char)c;
      }
    }
  }

  return 0;
}
/* USER CODE END 0 */

/**
 * @brief  The application entry point.
 * @retval int
 */
int main(void)
{

  /* MCU Configuration--------------------------------------------------------*/

  /* Reset of all peripherals, Initializes the Flash interface and the Systick. */
  HAL_Init();

  /* Configure the system clock */
  SystemClock_Config();

  /* Initialize all configured peripherals */
  MX_GPIO_Init();
  MX_USB_DEVICE_Init();
  MX_TIM4_Init();
  MX_TIM8_Init();
  /* USER CODE BEGIN 2 */
  for (int i = 0; i < 20; i++)
  {
    HAL_GPIO_TogglePin(LED_PC13_GPIO_Port, LED_PC13_Pin);
    HAL_Delay(80);
  }
  HAL_GPIO_WritePin(LED_PC13_GPIO_Port, LED_PC13_Pin, GPIO_PIN_SET);
  HAL_GPIO_WritePin(STEP_EN_GPIO_Port, STEP_EN_Pin, GPIO_PIN_SET);

  HAL_GPIO_WritePin(STEP_MS1_GPIO_Port, STEP_MS1_Pin, GPIO_PIN_SET);
  HAL_GPIO_WritePin(STEP_MS2_GPIO_Port, STEP_MS2_Pin, GPIO_PIN_SET);
  // MS2/MS1 = 0/0 => MicroStep 1/8
  // MS2/MS1 = 0/1 => MicroStep 1/32
  // MS2/MS1 = 1/0 => MicroStep 1/64
  // MS2/MS1 = 1/1 => MicroStep 1/16

  HAL_TIM_PWM_Stop(&htim8, TIM_CHANNEL_1);
  HAL_TIM_PWM_Stop(&htim8, TIM_CHANNEL_2);
  HAL_TIM_PWM_Stop(&htim8, TIM_CHANNEL_3);

  // Stepper_Start();

  /* USER CODE END 2 */

  /* Infinite loop */
  /* USER CODE BEGIN WHILE */
  while (1)
  {
    Serial_process_commands();
    /* USER CODE END WHILE */

    /* USER CODE BEGIN 3 */
  }
  /* USER CODE END 3 */
}

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
/**
 * @brief  Period elapsed callback in non blocking mode
 * @note   This function is called  when TIM2 interrupt took place, inside
 * HAL_TIM_IRQHandler(). It makes a direct call to HAL_IncTick() to increment
 * a global variable "uwTick" used as application time base.
 * @param  htim : TIM handle
 * @retval None
 */
void HAL_TIM_PeriodElapsedCallback(TIM_HandleTypeDef *htim)
{
  if (htim->Instance == TIM2)
  {
    HAL_IncTick();
  }
}

/**
 * @brief  This function is executed in case of error occurrence.
 * @retval None
 */
void Error_Handler(void)
{
  /* USER CODE BEGIN Error_Handler_Debug */
  /* User can add his own implementation to report the HAL error return state */
  __disable_irq();
  while (1)
  {
  }
  /* USER CODE END Error_Handler_Debug */
}
#ifdef USE_FULL_ASSERT
/**
 * @brief  Reports the name of the source file and the source line number
 *         where the assert_param error has occurred.
 * @param  file: pointer to the source file name
 * @param  line: assert_param error line source number
 * @retval None
 */
void assert_failed(uint8_t *file, uint32_t line)
{
  /* USER CODE BEGIN 6 */
  /* User can add his own implementation to report the file name and line number,
     ex: printf("Wrong parameters value: file %s on line %d\r\n", file, line) */
  /* USER CODE END 6 */
}
#endif /* USE_FULL_ASSERT */

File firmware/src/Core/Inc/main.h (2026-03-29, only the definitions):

#define LED_PC13_Pin GPIO_PIN_13
#define LED_PC13_GPIO_Port GPIOC
#define DCMotor_PWM3_Pin GPIO_PIN_6
#define DCMotor_PWM3_GPIO_Port GPIOC
#define DCMotor_PWM2_Pin GPIO_PIN_7
#define DCMotor_PWM2_GPIO_Port GPIOC
#define DCMotor_PWM1_Pin GPIO_PIN_8
#define DCMotor_PWM1_GPIO_Port GPIOC
#define STEP_EN_Pin GPIO_PIN_5
#define STEP_EN_GPIO_Port GPIOB
#define STEP_MS1_Pin GPIO_PIN_6
#define STEP_MS1_GPIO_Port GPIOB
#define STEP_MS2_Pin GPIO_PIN_7
#define STEP_MS2_GPIO_Port GPIOB
#define STEP_PWM_Pin GPIO_PIN_8
#define STEP_PWM_GPIO_Port GPIOB
#define STEP_DIR_Pin GPIO_PIN_9
#define STEP_DIR_GPIO_Port GPIOB

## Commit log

2026-03-29 add step, dc motor lib software
    [DucMinh-B_Cu.gbr, DucMinh-B_Mask.gbr, DucMinh-B_Paste.gbr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]
2026-03-29 add Readme.md, fix cmd interface
    [main.c, main.h]

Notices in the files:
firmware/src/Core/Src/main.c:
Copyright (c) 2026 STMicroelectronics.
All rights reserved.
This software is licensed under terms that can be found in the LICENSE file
